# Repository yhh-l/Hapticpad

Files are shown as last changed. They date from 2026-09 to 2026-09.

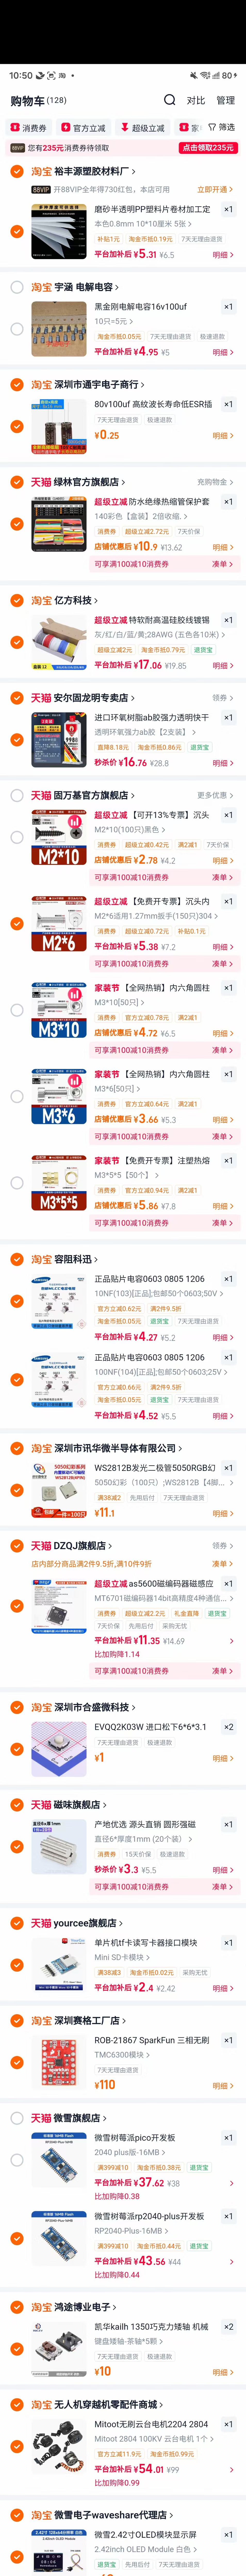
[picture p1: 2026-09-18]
domestic-bom-cart.jpg

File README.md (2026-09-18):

# CNCDan - Haptic Pad

[中文复刻、国内采购与 3D 打印说明](README_CN.md)

> This repository is a fork/reproduction of the original [dmcke5/Hapticpad](https://github.com/dmcke5/Hapticpad) project. Original mechanical, PCB and software designs belong to dmcke5 / CNCDan and remain under the original `CERN-OHL-S-2.0` license.

Haptic Pad

A 6 button macropad with a display for button labels and a mouse knob with haptic feedback!

[Project Video Link](https://youtu.be/bNUKRJQjuvQ)

#### Features

- 6 programmable macro buttons
- 128x64 OLED display for button labels and icons
- Support for up to 256 profiles for a total of 1536 macros
- Easy XML configuration, no special drivers required
- Macro button combinations can be configured with up to 3 simultaneous buttons or 3 separate button presses with configurable delays between them
- Micro SD storage for button labels and config files
- Haptic feedback mouse wheel with three different modes: Clicky, Twist and Momentum
- RGB ring with configurable colours and 5 different display modes: Halo, Bands, Breath, Rainbow, Solid and Off
- Easy profile switching with up/down profile buttons or profile list display
- The last profile is stored on the SD card, so the macro pad starts on the profile that was last active

#### Bill of Materials

The list below reflects the parts selected for this fork/build. Links point to the exact part or the closest stable manufacturer/distributor page available.

- 1x [Waveshare 2.42-inch 128x64 OLED display](https://www.waveshare.com/product/ai/2.42inch-oled-module.htm)
- 1x [MT6701 magnetic encoder module](https://www.aliexpress.com/item/1005007469177411.html), configured for ABZ incremental output at 1024 PPR
  - Use the encoder's dedicated diametrically/radially magnetized magnet. The 6x1mm magnets below are only for the wheel coupling.
- 1x [2804 100KV brushless gimbal motor](https://www.aliexpress.com/item/1005006008489660.html) with a hollow shaft
- 6x [Kailh Choc V1 low-profile switches](https://www.aliexpress.com/item/1005005066585322.html)
- 1x [Waveshare RP2040-Plus](https://docs.waveshare.com/RP2040-Plus), 16MB without pre-soldered headers (SKU 23503)
- 1x [SparkFun TMC6300 3-phase motor driver board, ROB-21867](https://www.sparkfun.com/sparkfun-brushless-motor-driver-3-phase-tmc6300.html)
- 1x [Micro SD module](https://www.aliexpress.com/item/1005010587984346.html)
  - A FAT32-formatted Micro SD card is also required; this build already has one.
- 4x [6x1mm magnets](https://www.aliexpress.com/item/1005009894772141.html)
- 2x [Panasonic EVQ-Q2K03W tactile buttons](https://www.digikey.com/en/products/detail/panasonic-electronic-components/EVQ-Q2K03W/762893)
  - The original BOM specifies EVQ-Q2B03W. Check installed height and mechanical fit before final assembly.
- 1x [10nF / 50V / 0603 / 103 X7R capacitor, LCSC C307346](https://www.lcsc.com/search?q=C307346) for controller-board C1

The following parts are optional if you want to include the LEDs:

- 20x [Worldsemi WS2812B-B/W, 5050 / PLCC4, LCSC C114586](https://www.lcsc.com/zh-TW/product-detail/RGB-LEDs_Worldsemi-WS2812B-B-W_C114586.html)
  - Do not use the WS2812B 2020 package; it does not match the PCB footprint.
- 20x [0.1uF (100nF) 0603 capacitors](https://www.aliexpress.com/item/32966526545.html)

#### Hardware

- 9x [M3x5x5 threaded inserts](https://www.aliexpress.com/w/wholesale-m3x5x5-threaded-insert.html) (only needed for the printed housing)
- 3x [M3x6 socket-head cap screws](https://www.aliexpress.com/w/wholesale-m3x6-socket-head-screw.html)
- 2x [M3x10 socket-head cap screws](https://www.aliexpress.com/w/wholesale-m3x10-socket-head-screw.html)
- 10x [M2.5x4 socket-head cap screws](https://www.aliexpress.com/w/wholesale-m2.5x4-socket-head-screw.html)
- 4x [M2x6 countersunk screws](https://www.aliexpress.com/w/wholesale-m2x6-countersunk-screw.html) (the original README incorrectly listed M3x6)
- 2x [M2x6 pan-head/self-tapping screws](https://www.aliexpress.com/w/wholesale-m2x6-self-tapping-screw.html) for the encoder mount (missing from the original BOM; an M2x4/6/8 assortment is useful if fit is uncertain)

### Printing Instructions

#### Printed version

Print all files in the `3D Files/STL's` folder. You will need 6 of the keycap file, 2 of the Menu button file and 2 of the PCB spacer file.

> [!WARNING]
> Uploading `Macro Pad - Printed Version.STL` may trigger a thin-wall warning for the main housing because the LED support features are too thin. Do not ignore the warning blindly: request a manual engineering review or thicken the LED supports before printing. If you print the file as-is, inspect the supports carefully and avoid applying force while fitting the LEDs.

#### Machined version

Print all files in the `3D Files/STL's` folder except `Custom Keycap.STL`, `Macro Pad - Printed Version.STL` and `Menu Button Printed.STL`.

Get all of the `.STEP` files in the `3D Files/STEP` folder machined. Do not include the Macropad Assembly `.STEP` file from the main directory, as it is a complete model of the Macro Pad rather than an individual part. If you supply the `MacroPad Housing.PDF` file with the housing, you can have the mounting holes tapped for you.

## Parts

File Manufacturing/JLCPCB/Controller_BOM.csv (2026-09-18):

Comment | Designator | Footprint | LCSC Part #
10nF 50V X7R | C1 | 0603 | C307346

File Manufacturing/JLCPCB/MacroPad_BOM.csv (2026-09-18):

Comment | Designator | Footprint | LCSC Part #
100nF 50V X7R | C2,C3,C4,C5,C6,C7,C8,C9,C10,C11,C12,C13,C14,C15,C16,C17,C18,C19,C20,C21 | 0603 | C14663
WS2812B-B/W | D1,D2,D3,D4,D5,D6,D7,D8,D9,D10,D11,D12,D13,D14,D15,D16,D17,D18,D19,D20 | SMD5050-4P | C114586
Panasonic EVQ-Q2K03W | S1,S2 | 6.5x6.0mm SMD

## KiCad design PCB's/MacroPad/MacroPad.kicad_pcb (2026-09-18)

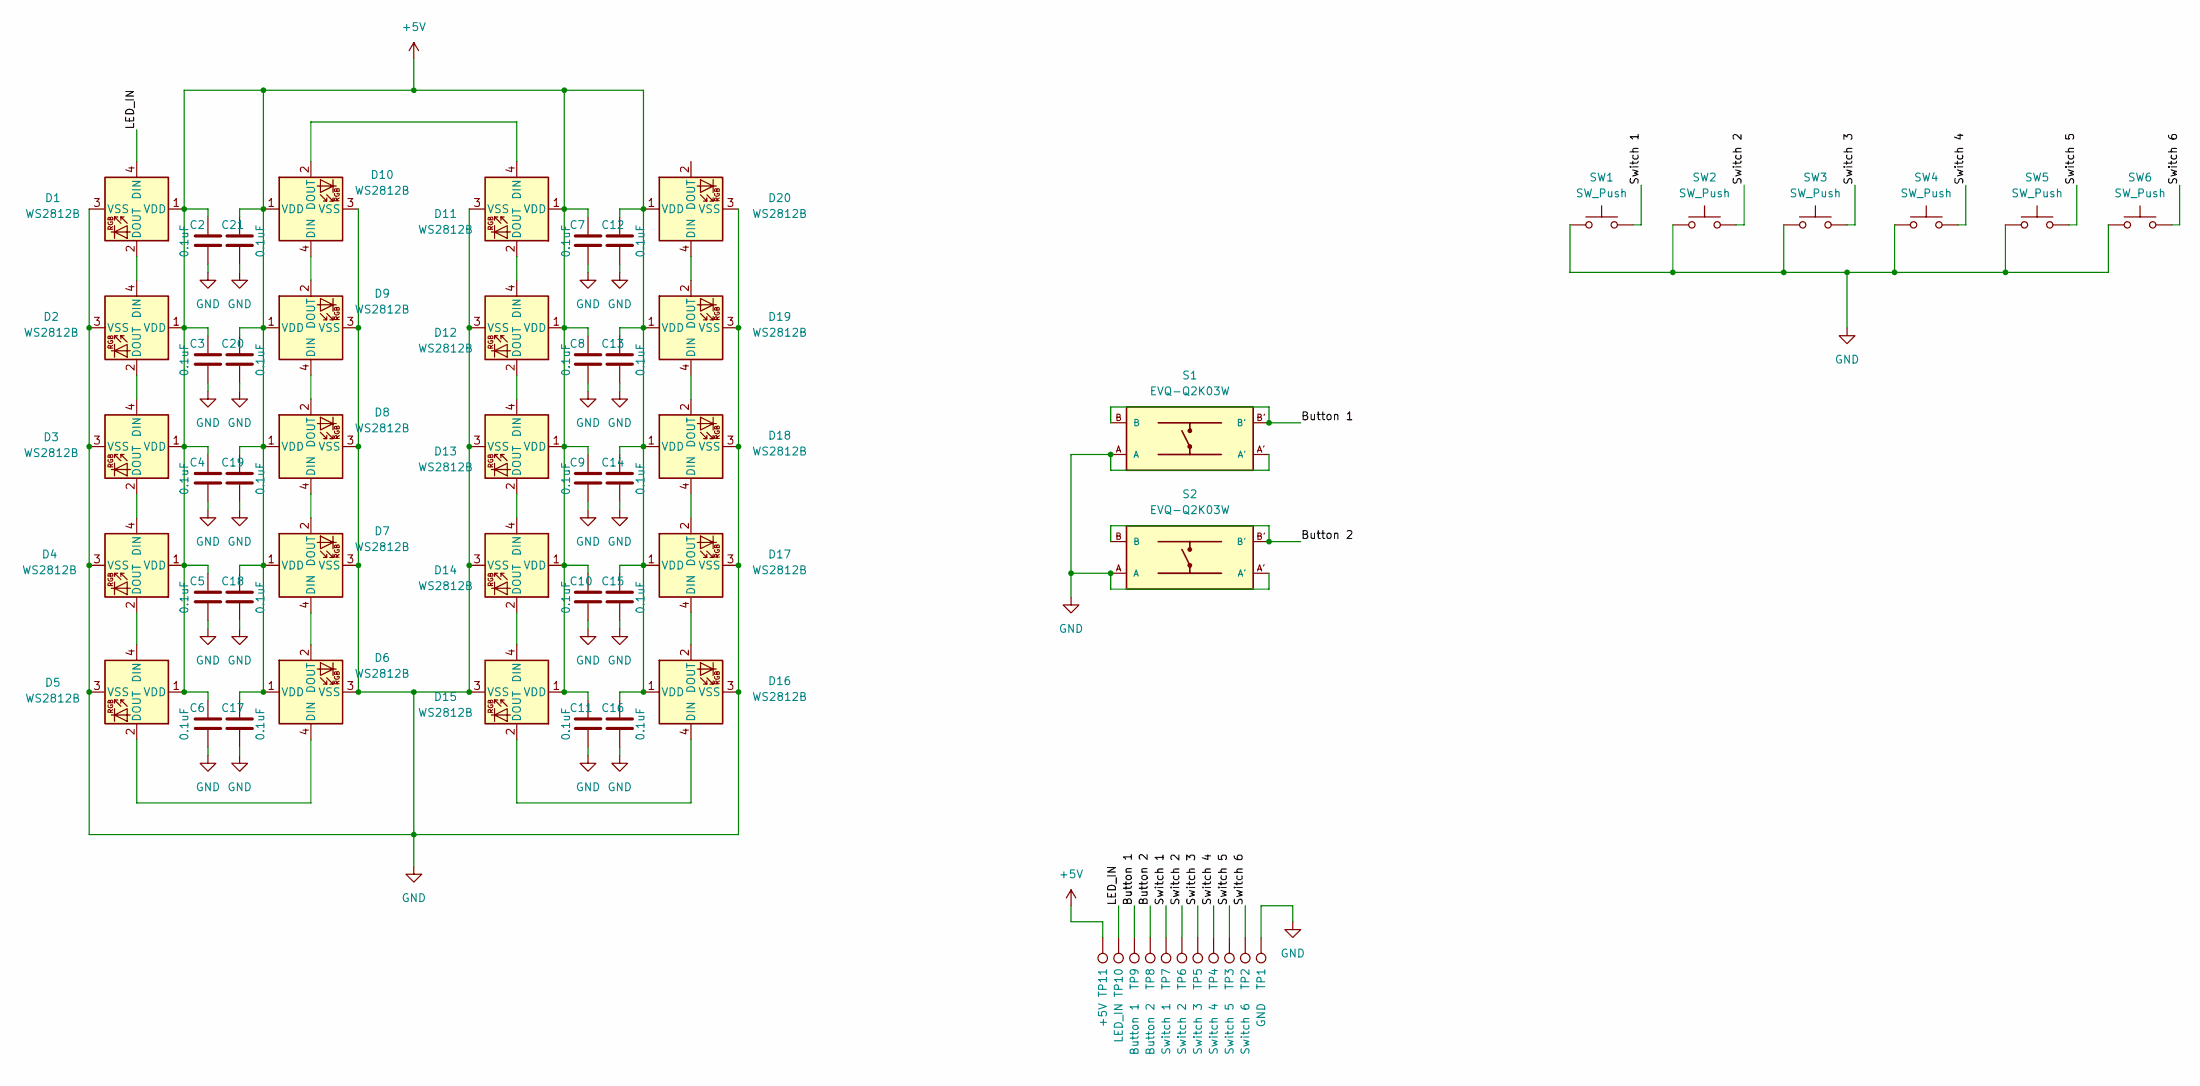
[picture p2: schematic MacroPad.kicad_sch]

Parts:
C2, C3, C4, C5, C6, C7, C8, C9, C10, C11, C12, C13, C14, C15, C16, C17, C18, C19, C20, C21: 0.1uF; C_0603_1608Metric
D1, D2, D3, D4, D5, D6, D7, D8, D9, D10, D11, D12, D13, D14, D15, D16, D17, D18, D19, D20: WS2812B; LED_WS2812B_PLCC4_5.0x5.0mm_P3.2mm
S1, S2: EVQ-Q2K03W; SW_EVQ-Q2B02W
SW1, SW2, SW3, SW4, SW5, SW6: SW_Push; SW_PG1350_reversible
TP1: GND; TestPoint_THTPad_D1.0mm_Drill0.5mm
TP2: Switch 6; TestPoint_THTPad_D1.0mm_Drill0.5mm
TP3: Switch 5; TestPoint_THTPad_D1.0mm_Drill0.5mm
TP4: Switch 4; TestPoint_THTPad_D1.0mm_Drill0.5mm
TP5: Switch 3; TestPoint_THTPad_D1.0mm_Drill0.5mm
TP6: Switch 2; TestPoint_THTPad_D1.0mm_Drill0.5mm
TP7: Switch 1; TestPoint_THTPad_D1.0mm_Drill0.5mm
TP8: Button 2; TestPoint_THTPad_D1.0mm_Drill0.5mm
TP9: Button 1; TestPoint_THTPad_D1.0mm_Drill0.5mm
TP10: LED_IN; TestPoint_THTPad_D1.0mm_Drill0.5mm
TP11: +5V; TestPoint_THTPad_D1.0mm_Drill0.5mm

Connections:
+5V: C2.1, C3.1, C4.1, C5.1, C6.1, C7.1, C8.1, C9.1, C10.1, C11.1, C12.1, C13.1, C14.1, C15.1, C16.1, C17.1, C18.1, C19.1, C20.1, C21.1, D1.1 (VDD), D2.1 (VDD), D3.1 (VDD), D4.1 (VDD), D5.1 (VDD), D6.1 (VDD), D7.1 (VDD), D8.1 (VDD), D9.1 (VDD), D10.1 (VDD), D11.1 (VDD), D12.1 (VDD), D13.1 (VDD), D14.1 (VDD), D15.1 (VDD), D16.1 (VDD), D17.1 (VDD), D18.1 (VDD), D19.1 (VDD), D20.1 (VDD), TP11.1
/Button 1: S1.B, S1.B', TP9.1
/Button 2: S2.B, S2.B', TP8.1
/LED_IN: D1.4 (DIN), TP10.1
/Switch 1: SW1.2, TP7.1
/Switch 2: SW2.2, TP6.1
/Switch 3: SW3.2, TP5.1
/Switch 4: SW4.2, TP4.1
/Switch 5: SW5.2, TP3.1
/Switch 6: SW6.2, TP2.1
GND: C2.2, C3.2, C4.2, C5.2, C6.2, C7.2, C8.2, C9.2, C10.2, C11.2, C12.2, C13.2, C14.2, C15.2, C16.2, C17.2, C18.2, C19.2, C20.2, C21.2, D1.3 (VSS), D2.3 (VSS), D3.3 (VSS), D4.3 (VSS), D5.3 (VSS), D6.3 (VSS), D7.3 (VSS), D8.3 (VSS), D9.3 (VSS), D10.3 (VSS), D11.3 (VSS), D12.3 (VSS), D13.3 (VSS), D14.3 (VSS), D15.3 (VSS), D16.3 (VSS), D17.3 (VSS), D18.3 (VSS), D19.3 (VSS), D20.3 (VSS), S1.A, S1.A', S2.A, S2.A', SW1.1, SW2.1, SW3.1, SW4.1, SW5.1, SW6.1, TP1.1
unnamed: D1.2 (DOUT), D2.4 (DIN)
unnamed: D2.2 (DOUT), D3.4 (DIN)
unnamed: D3.2 (DOUT), D4.4 (DIN)
unnamed: D4.2 (DOUT), D5.4 (DIN)
unnamed: D5.2 (DOUT), D6.4 (DIN)
unnamed: D6.2 (DOUT), D7.4 (DIN)
unnamed: D7.2 (DOUT), D8.4 (DIN)
unnamed: D8.2 (DOUT), D9.4 (DIN)
unnamed: D9.2 (DOUT), D10.4 (DIN)
unnamed: D10.2 (DOUT), D11.4 (DIN)
unnamed: D11.2 (DOUT), D12.4 (DIN)
unnamed: D12.2 (DOUT), D13.4 (DIN)
unnamed: D13.2 (DOUT), D14.4 (DIN)
unnamed: D14.2 (DOUT), D15.4 (DIN)
unnamed: D15.2 (DOUT), D16.4 (DIN)
unnamed: D16.2 (DOUT), D17.4 (DIN)
unnamed: D17.2 (DOUT), D18.4 (DIN)
unnamed: D18.2 (DOUT), D19.4 (DIN)
unnamed: D19.2 (DOUT), D20.4 (DIN)

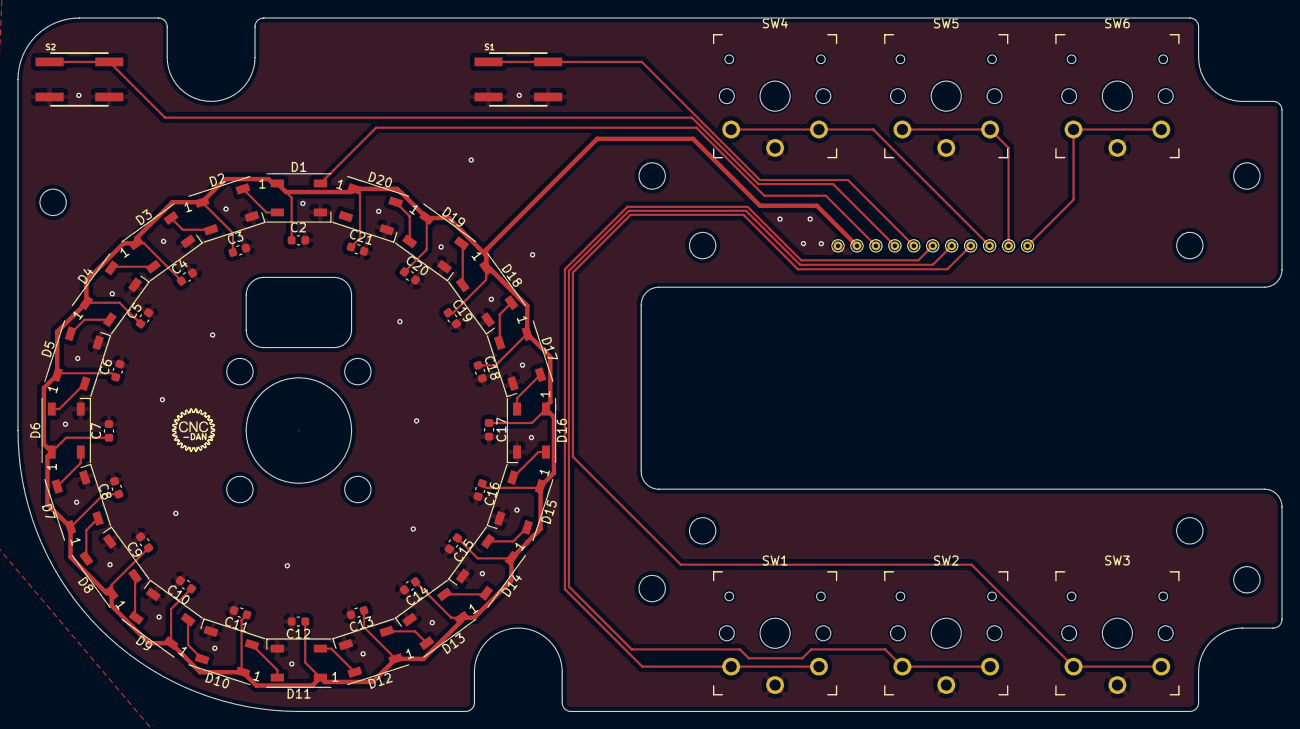
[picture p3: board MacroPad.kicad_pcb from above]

Board: 2 copper layers, 144.0 x 79.0 mm, 59 parts (0 on the bottom side), 30 nets.

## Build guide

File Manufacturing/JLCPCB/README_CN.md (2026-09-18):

# 嘉立创 PCBA 参考文件

本目录的 BOM 和 CPL/坐标文件由当前 KiCad PCB 源文件整理，用于以后选择嘉立创 SMT/PCBA 时参考。本次只下单裸 PCB，**不要上传这些文件**；主板和控制板仍然分别只上传对应的 Gerber ZIP。

## 文件对应关系

| PCB | BOM | CPL/坐标文件 |
|---|---|---|
| 主板 | `MacroPad_BOM.csv` | `MacroPad_CPL.csv` |
| 控制板 | `Controller_BOM.csv` | `Controller_CPL.csv` |

## 已核对内容

- 主板 BOM/CPL 包含 42 个顶层 SMD 位号：`C2-C21`、`D1-D20`、`S1-S2`。
- 控制板 BOM/CPL 只包含顶层 SMD 电容 `C1`；TMC6300、RP2040-Plus、排针和测试点不在贴片文件内，按本项目装配方式后焊。
- `C2-C21`：100nF / 50V / X7R / 0603，对应 [LCSC C14663](https://www.lcsc.com/product-detail/YAGEO-C14663.html)。
- `D1-D20`：Worldsemi `WS2812B-B/W`，SMD5050-4P，对应 [LCSC C114586](https://www.lcsc.com/product-detail/RGB-LEDs-Built-in-IC_Worldsemi-WS2812B-B-W_C114586.html)。
- `C1`：10nF / 50V / X7R / 0603，对应 [LCSC C307346](https://www.lcsc.com/product-detail/C307346.html)。
- `S1-S2`：已按本次采购改为 Panasonic [`EVQ-Q2K03W`](https://www.digikey.com/en/products/detail/panasonic-industry/EVQ-Q2K03W/762893)，6.5×6.0mm 顶按 SMD；当前未填写 LCSC 料号，上传 PCBA 时需要在嘉立创页面手动匹配、客供或设为不贴。
- KiCad 内部仍保留旧库名 `SW_EVQ-Q2B02W`，但元件 Value 已更新为 `EVQ-Q2K03W`。现有焊盘中心距为 6.8×4.0mm，与 K03W 的 J 型引脚间距一致，因此不改铜层和 Gerber。
- CPL 坐标、层和旋转角来自当前 `.kicad_pcb`，并按 Gerber 坐标系执行 `KiCad X/Y → Gerber X/-Y` 转换；所有列出的器件都位于顶层。LED 按环形布局每颗递增 18°。

> [!WARNING]
> BOM/CPL 能被识别不代表方向一定正确。真正下 PCBA 单时，必须在嘉立创贴片预览中逐一检查 `D1-D20` 的 1 脚/DIN-DOUT 方向，并确认 `S1-S2` 外形和焊盘重合。若平台匹配了替代料，也要重新核对封装和方向后再付款。

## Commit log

2026-09-18 Update BOM links and 3D-printing warning
    Document this build's component selections, add stable material links and hardware references, correct fastener notes, and warn that the main housing may trigger a thin-wall alert around the LED supports.
2026-09-18 Clarify bare PCB upload instructions
2026-09-18 Add current JLCPCB BOM and placement files
    [Controller_BOM.csv, MacroPad.kicad_pcb, MacroPad.kicad_sch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]
2026-09-18 Align JLCPCB placements with Gerber coordinates
    [Controller_BOM.csv, MacroPad_BOM.csv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]
2026-10-10 Document build hardware choices and LED orientation
